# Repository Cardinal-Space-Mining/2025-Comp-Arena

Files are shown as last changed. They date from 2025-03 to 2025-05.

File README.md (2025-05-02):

# 2025-Comp-Arena

This is the arena for the 2025 COSMIC Competition at ISU.

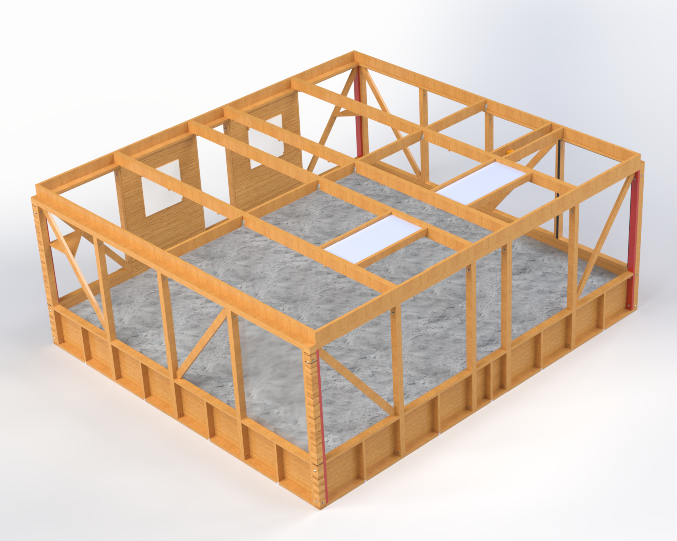
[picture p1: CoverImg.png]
arena image


## BOM
[here](https://docs.google.com/spreadsheets/d/1-_N2USS-mLNvjBXAtTUOFBfuuMwFibqy-OpLSeePz_4/edit?usp=sharing)

## Construction Outline
1. Recieve shipment of lumber on 5/16/2025 at 8 am when SICTR wood shop opens.
2. Use SICTR 1211 to cut wood to length, pre cut straps, and pre cut vapor barriers
3. Store cut wood over night 5/16 to 5/17 in SICTR 1248
4. Use SICTR 1211 to assemble arena Panels
5. Store fabbed Panels over night 5/17 to 5/18 in SICTR 1248
6. Assemble Panels into base arena
7. Store base arena overnight 5/18 - 5/19 in SICTR 1248
8. Have regolith delivered by sponsor, and moved in by FP&M
9. Emplace final vapor barrier
10. Install Dehumidifier
11. Store regolith and arena overnight 5/19 - 5/20 in SICTR 1248
12. Install cameras, shelves, visionary-S, and networking setup
13. Store regolith and arena overnight 5/20 - 5/21 in SICTR 1248
14. Checkin Begins

### Lumber Cuting Instructions
Cut boards according to this cut list:
```
For: 1x1, Cost: 35.0, Effiency: 84.82%
	Purchase List:
		(2) ankeny HomeDepot 1x1x10'
	Cut List:
		(1) ankeny HomeDepot 1x1x10' -> [3.0, 3.0, 3.0, 3.0, 3.0, 3.0, 3.0, 3.0, 3.0, 20.11, 20.11, 20.11, 31.0]
		(1) ankeny HomeDepot 1x1x10' -> [3.0, 3.0, 3.0, 3.0, 3.0, 3.0, 3.0, 3.0, 3.0, 3.0, 3.0, 3.0, 3.0, 3.0, 3.0, 3.0, 3.0, 20.11, 31.0]

For: 2x4, Cost: 230.79, Effiency: 83.63%
	Purchase List:
		(49) ames menards 2x4x12'
	Cut List:
		(1) ames menards 2x4x12' -> [21.0, 48.0]
		(4) ames menards 2x4x12' -> [21.0, 24.0, 48.0, 48.0]
		(5) ames menards 2x4x12' -> [21.0, 21.0, 21.0, 80.0]
		(8) ames menards 2x4x12' -> [24.0, 45.0, 73.2]
		(8) ames menards 2x4x12' -> [45.0, 80.0]
		(23) ames menards 2x4x12' -> [48.0, 80.0]

For: 2x6, Cost: 300.96, Effiency: 72.99%
	Purchase List:
		(18) ames menards 2x6x20'
	Cut List:
		(1) ames menards 2x6x20' -> [45.0, 45.0, 45.0, 45.0, 45.0]
		(1) ames menards 2x6x20' -> [45.0]
		(1) ames menards 2x6x20' -> [21.0, 196.0]
		(2) ames menards 2x6x20' -> [223.0]
		(2) ames menards 2x6x20' -> [24.0, 199.0]
		(2) ames menards 2x6x20' -> [45.0, 48.0, 48.0, 48.0, 48.0]
		(9) ames menards 2x6x20' -> [196.0]

```
Cut list generated by [CutListOptimizer1D](https://github.com/wimos-ai/CutListOptimizer1D)

### Panel Assembly Instructions

#### Basic Panel:

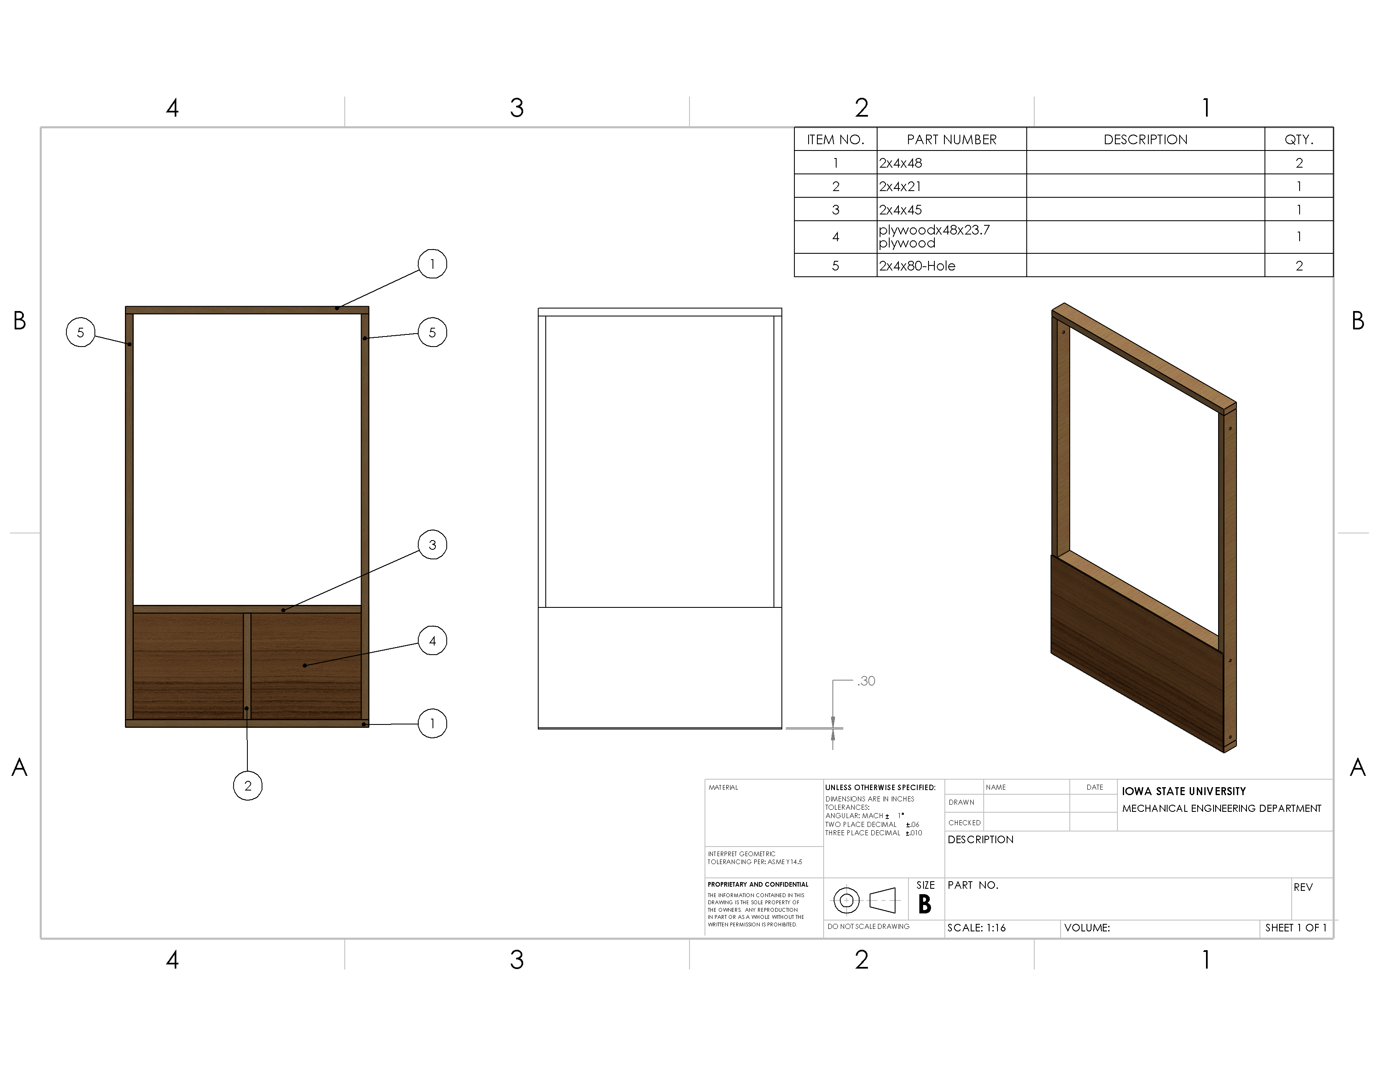
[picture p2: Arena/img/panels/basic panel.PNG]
Basic Panel png


#### Basic Panel (B):

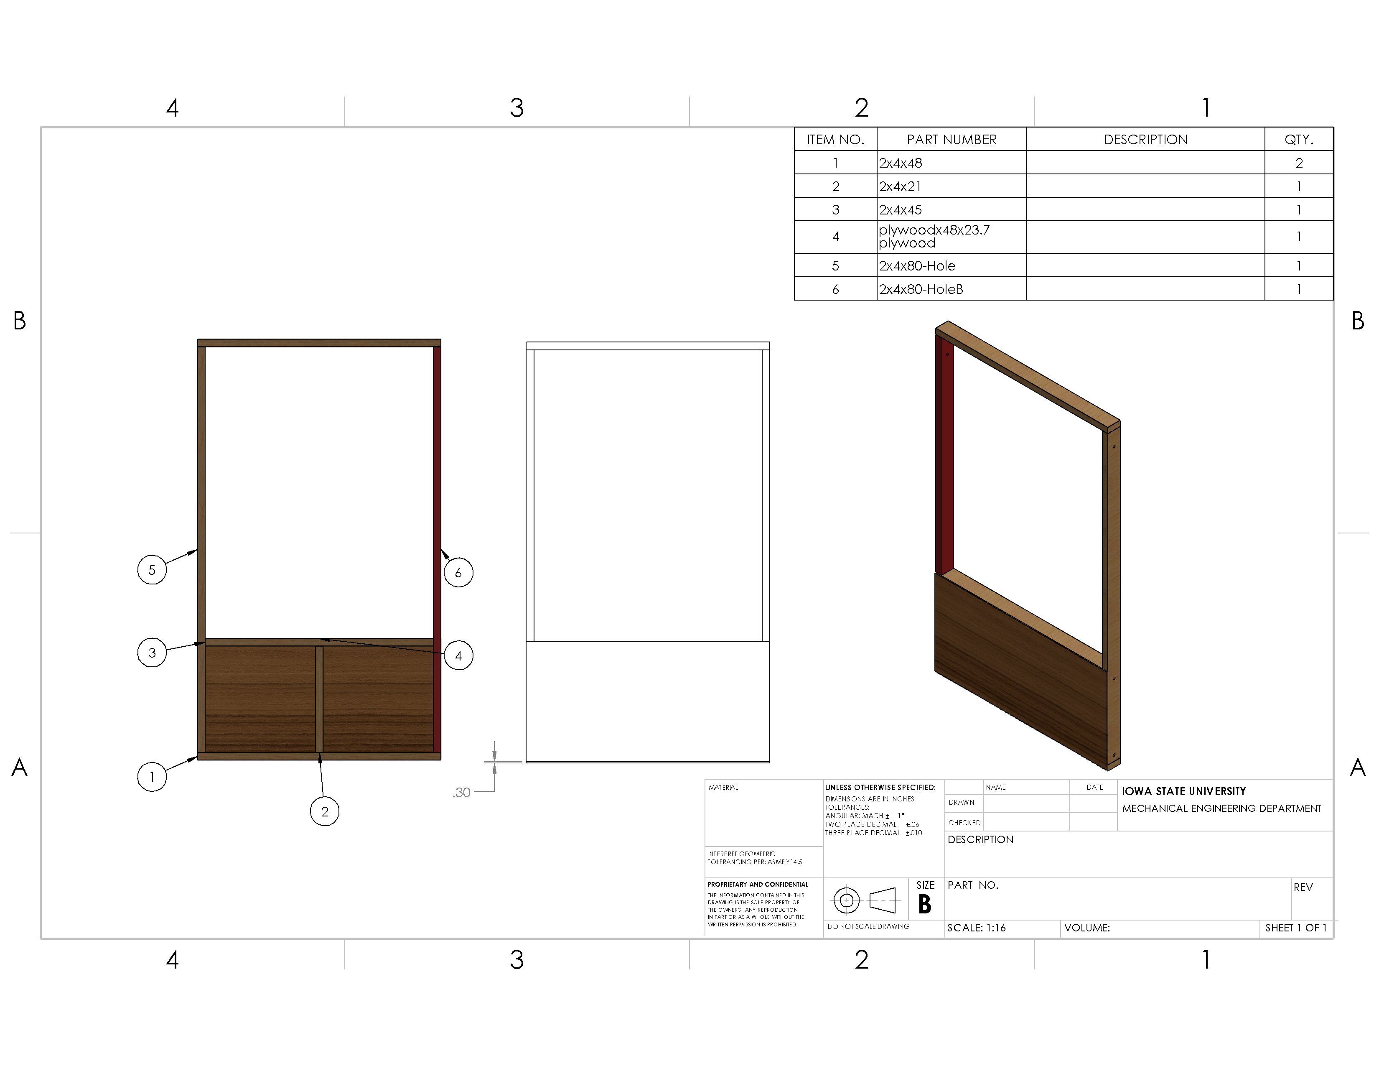
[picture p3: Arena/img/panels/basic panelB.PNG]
Basic Panel (B) png


#### Basic Panel (C):

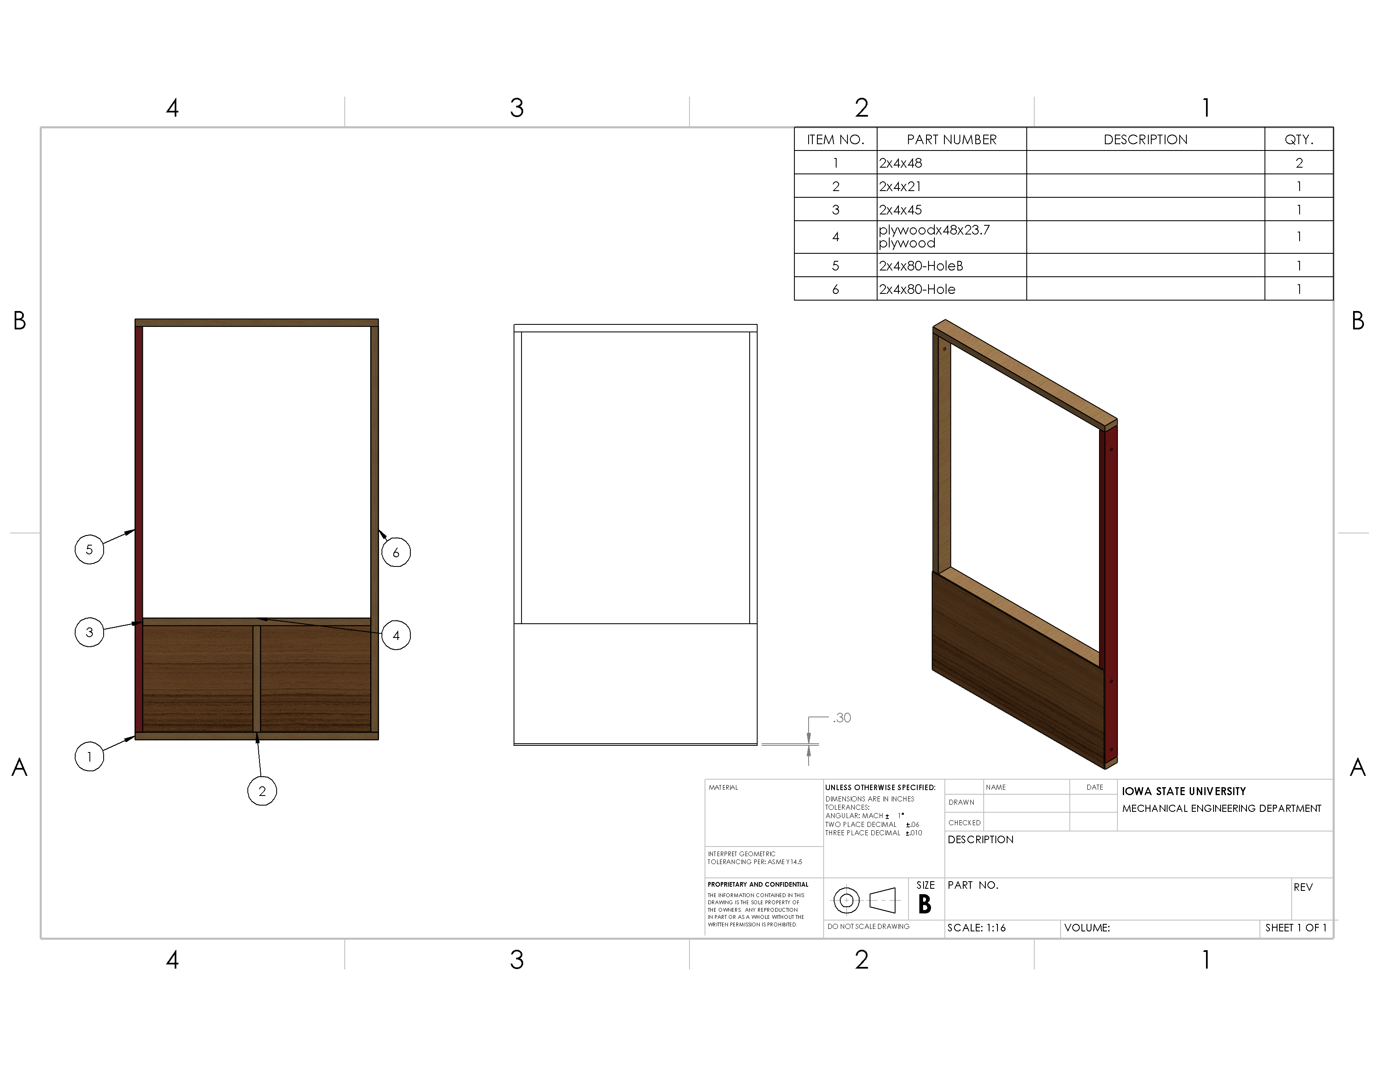
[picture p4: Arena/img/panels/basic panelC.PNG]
Basic Panel (C) png


#### Short Panel:

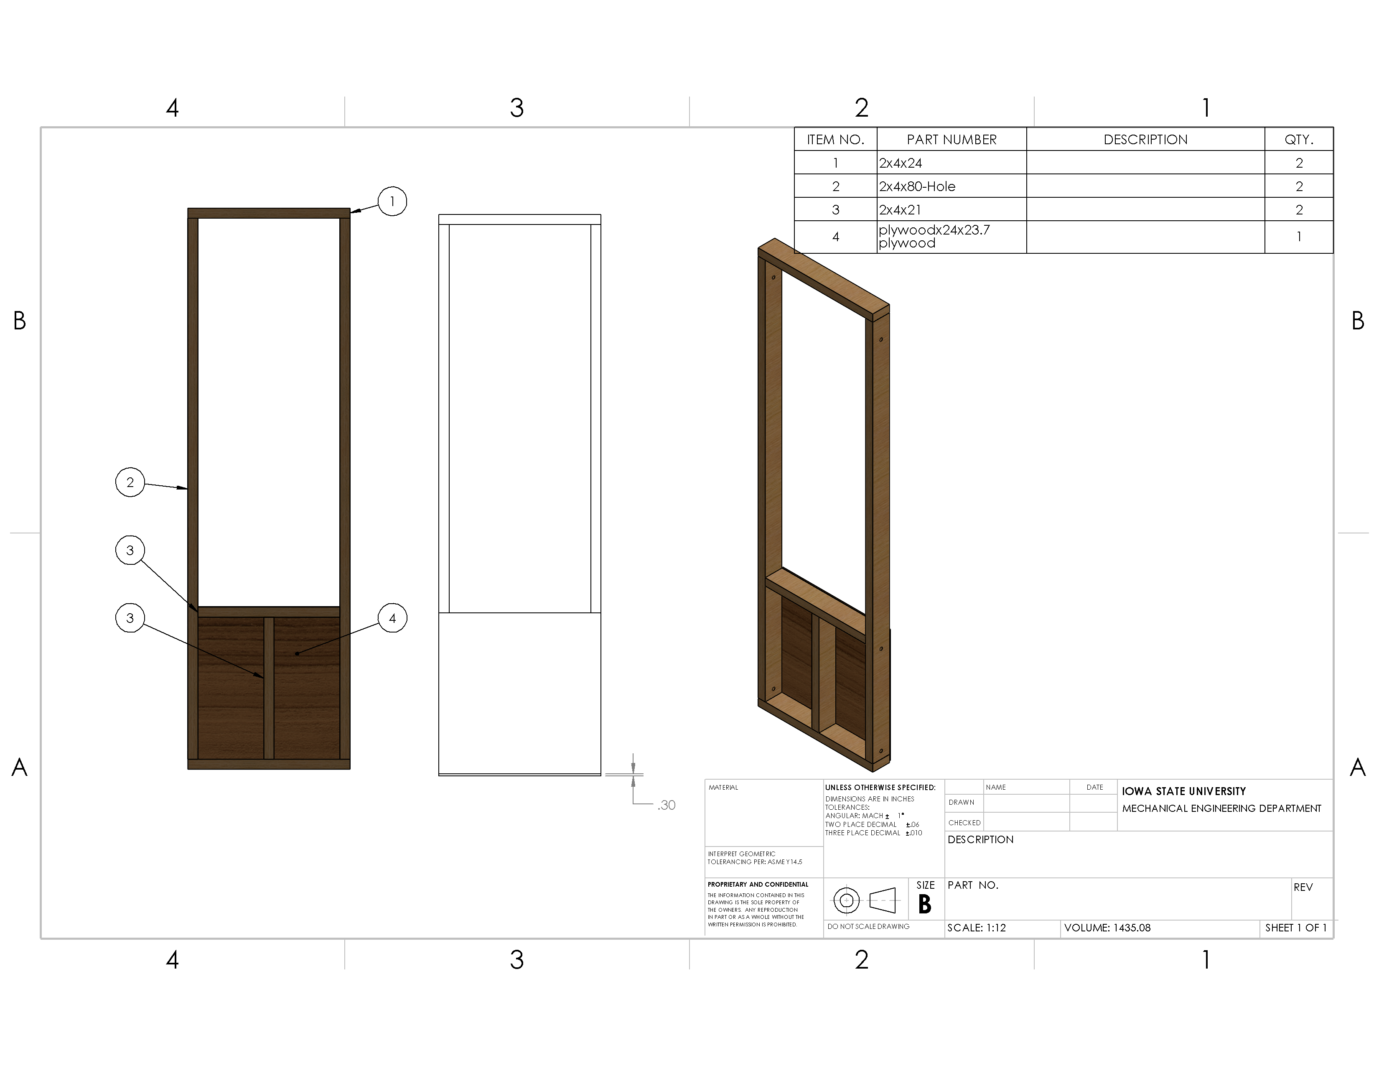
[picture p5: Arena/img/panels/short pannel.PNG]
Short Panel png


#### Door Panel:

It's just a basic panel with different sheeting

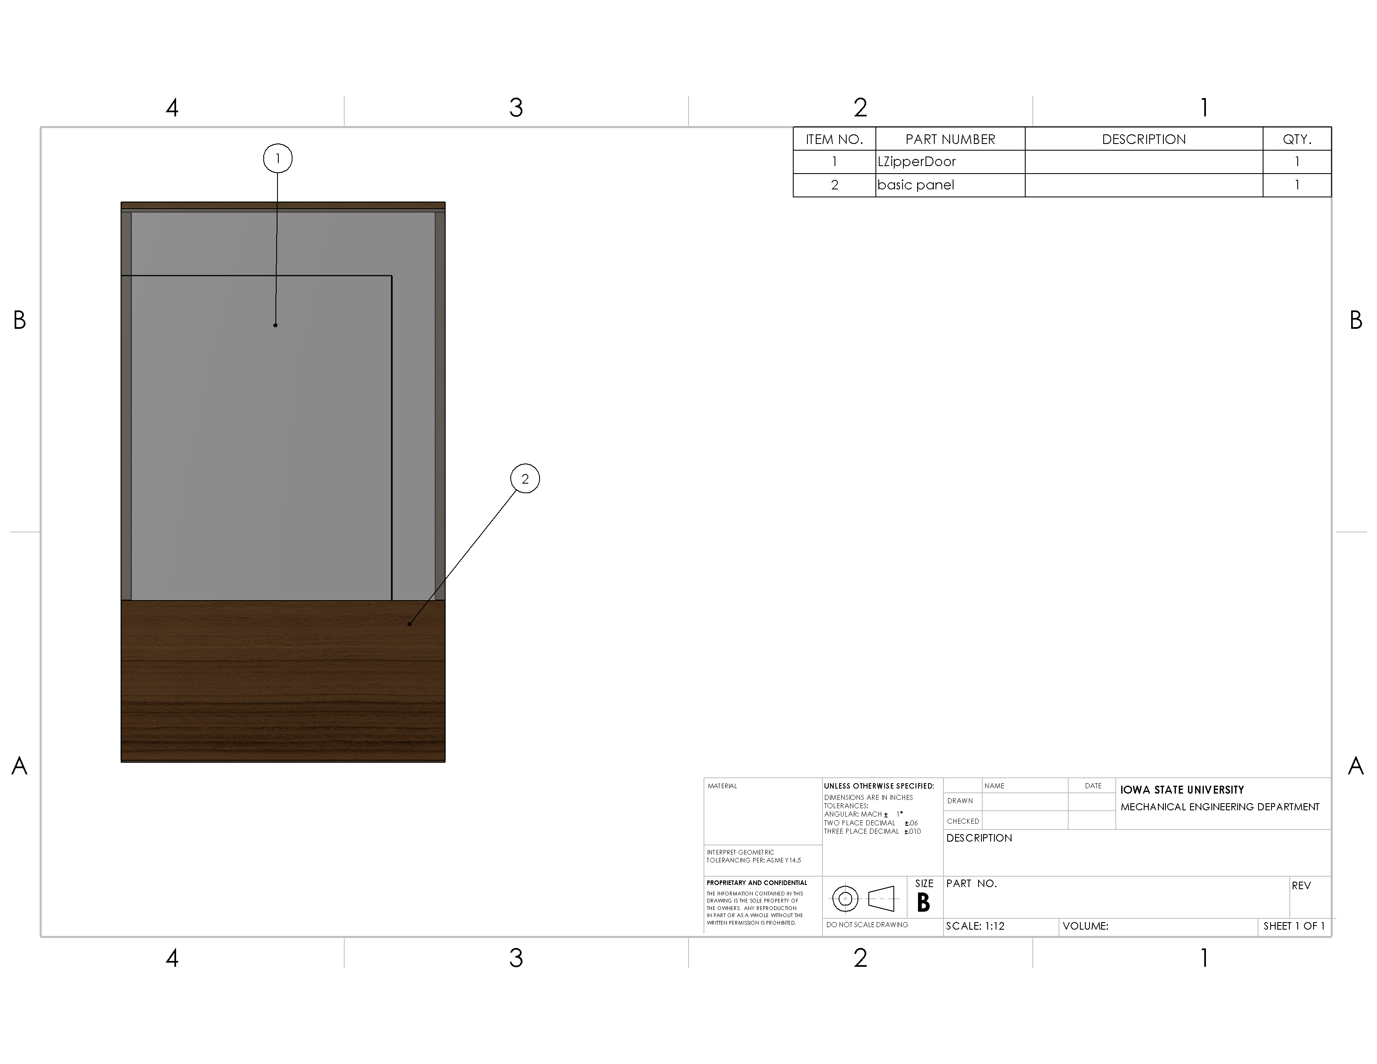
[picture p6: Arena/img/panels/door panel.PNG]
Door Panel png


#### Fan Panel:

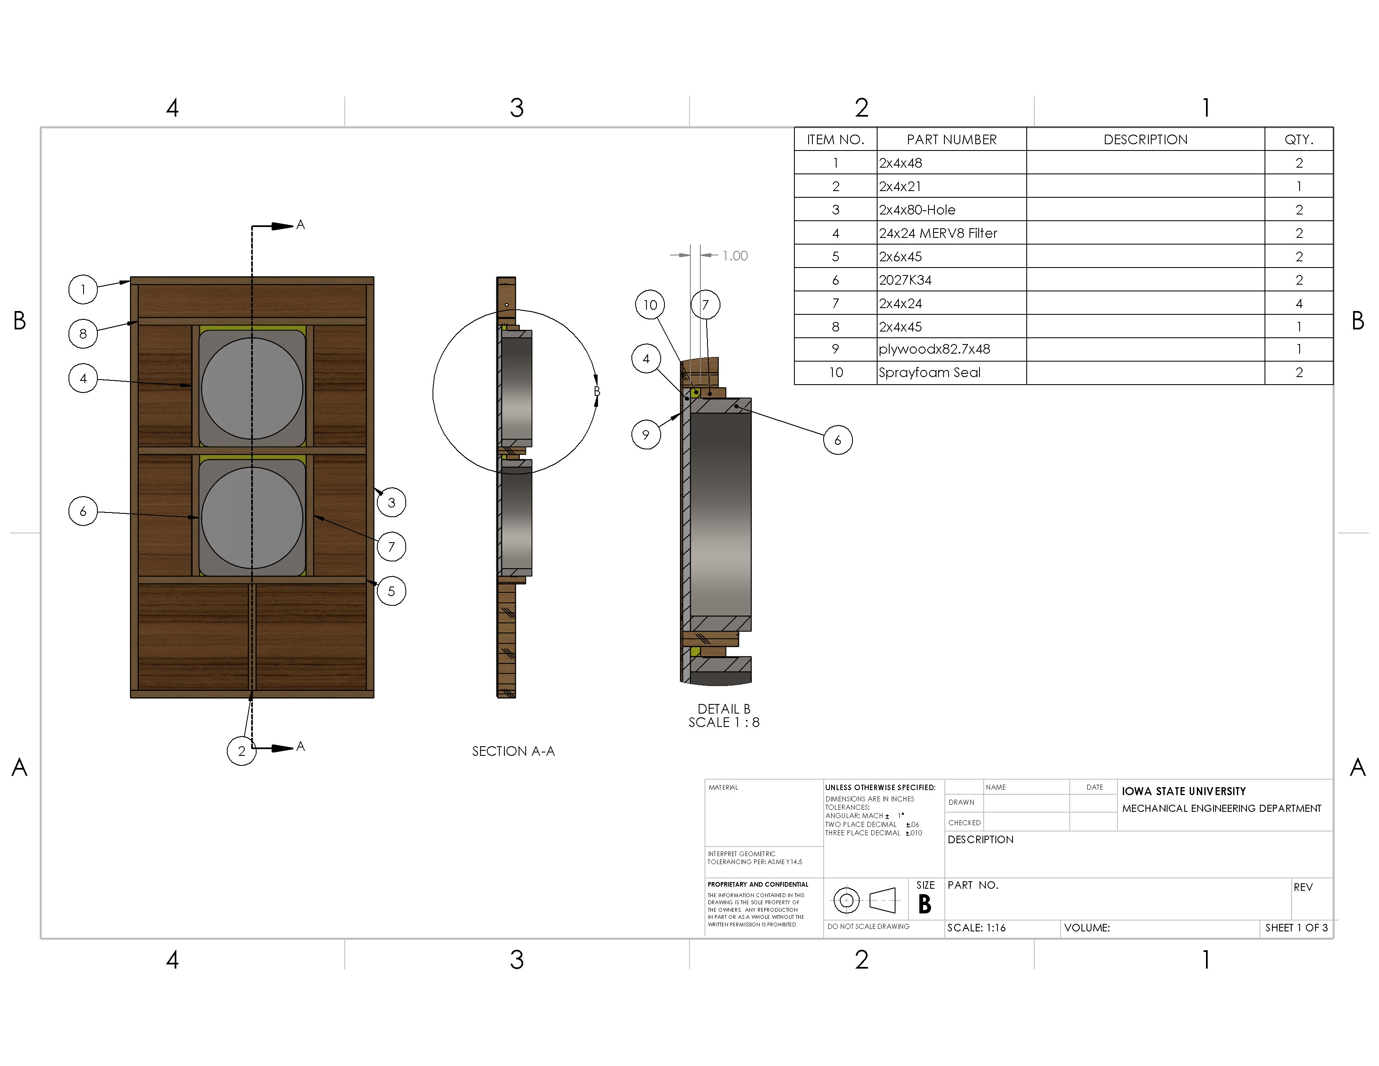
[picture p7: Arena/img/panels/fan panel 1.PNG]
Fan Panel (1) png


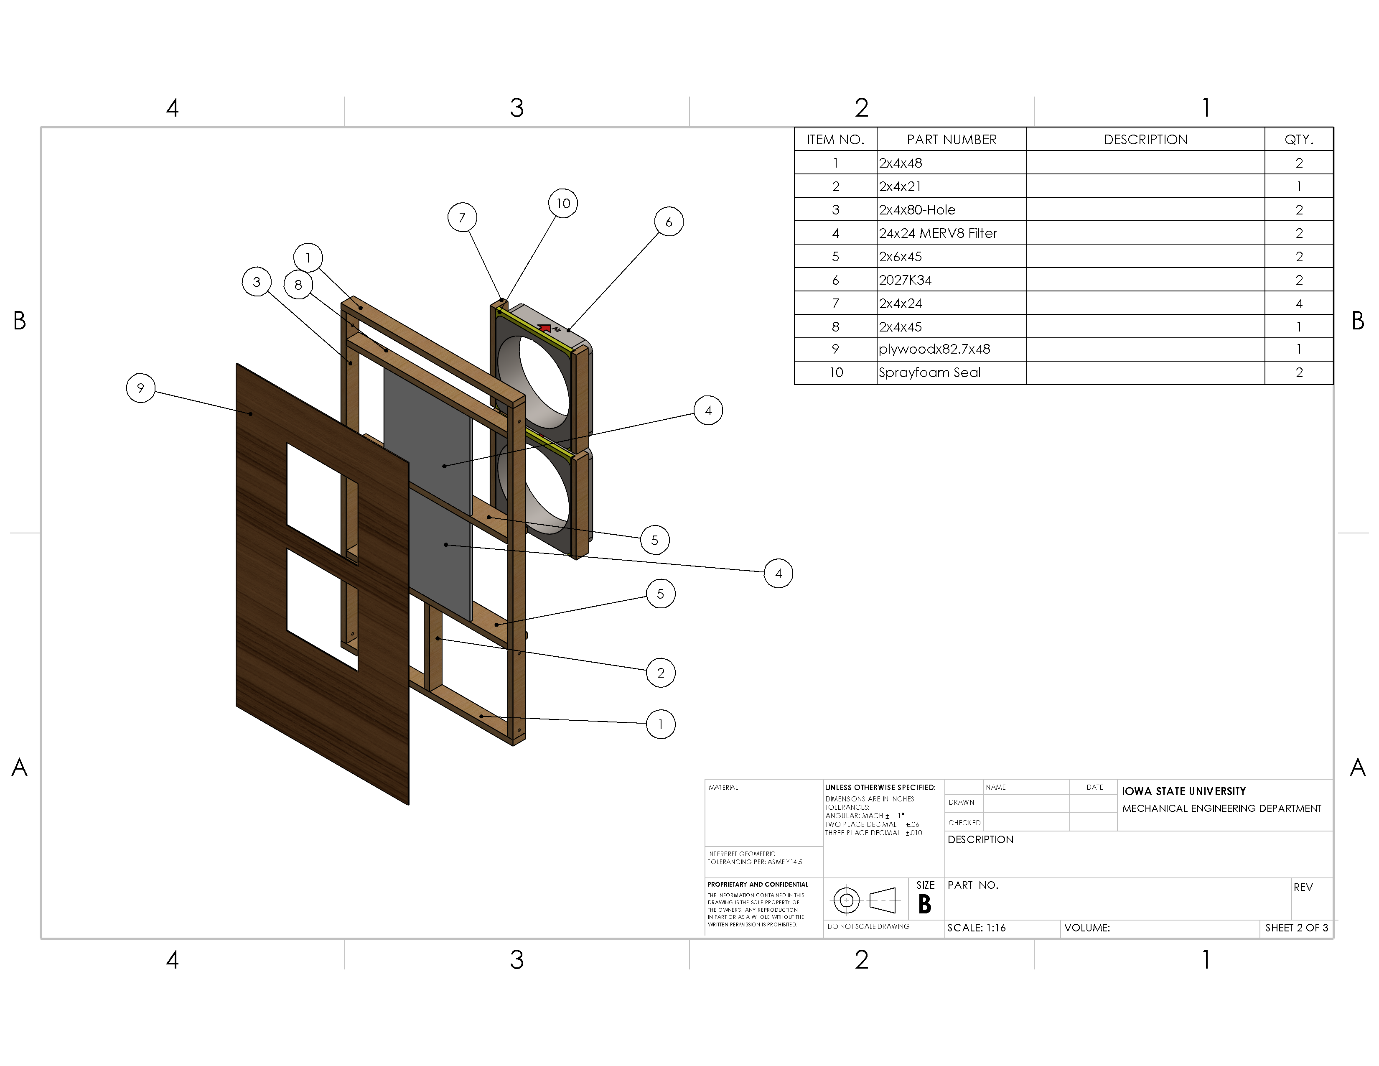
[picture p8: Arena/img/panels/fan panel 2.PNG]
Fan Panel (2) png


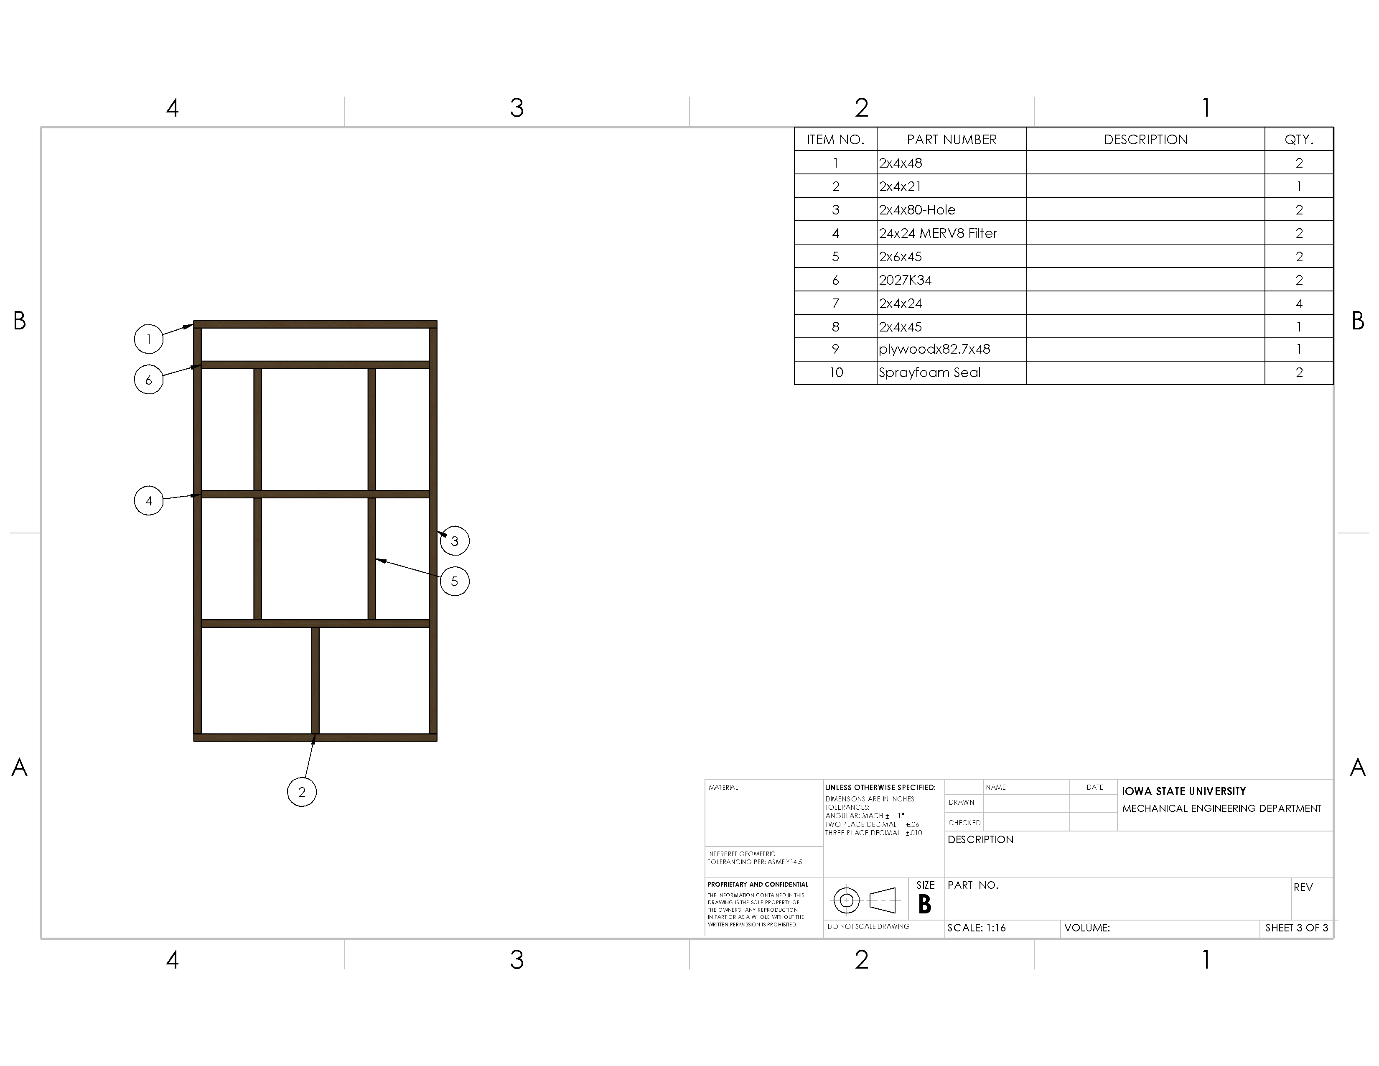
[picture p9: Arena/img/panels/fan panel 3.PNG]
Fan Panel (3) png


### Arena Assembly Instructions

1. Install Floor
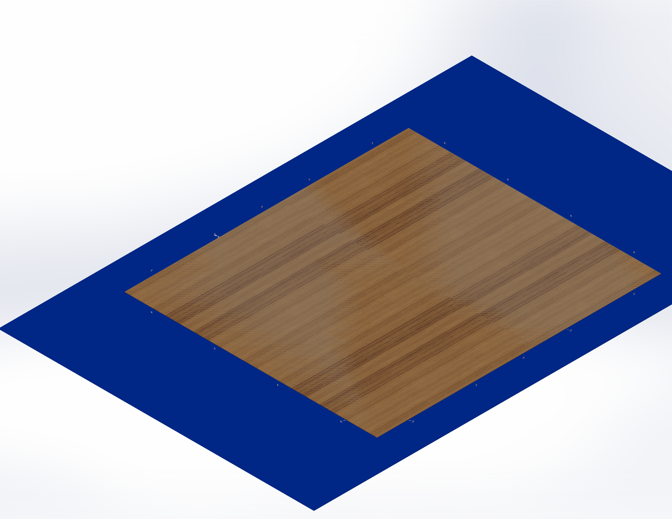
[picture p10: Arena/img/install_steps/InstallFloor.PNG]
Install Floor
	
2. Install Walls, Bracing, and Sheeting
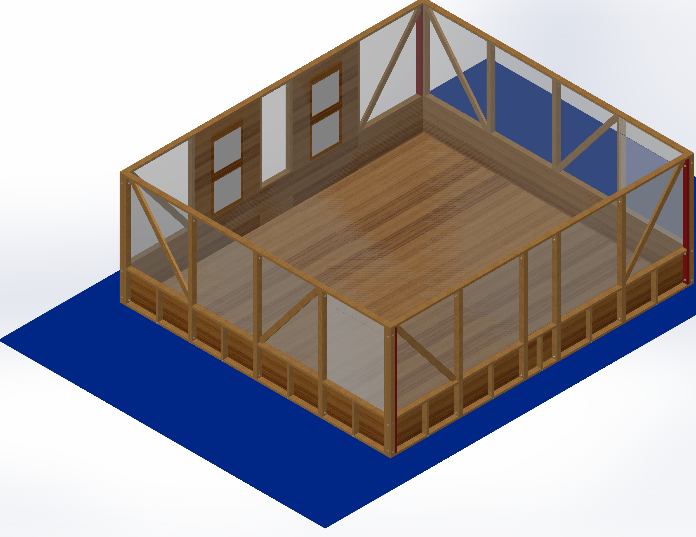
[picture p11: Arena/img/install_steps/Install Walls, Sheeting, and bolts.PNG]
Install Wall

3. Install Crown
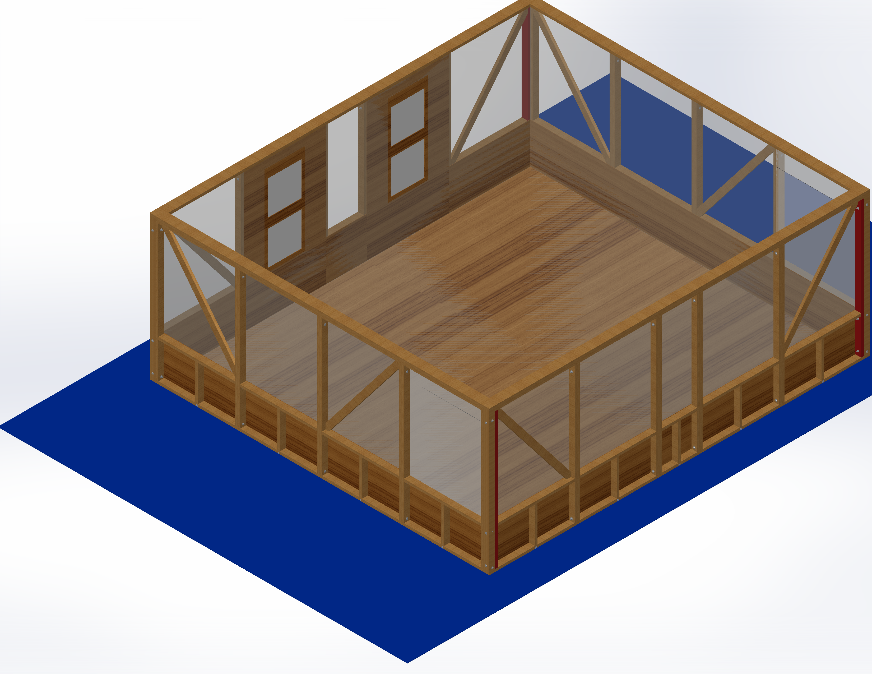
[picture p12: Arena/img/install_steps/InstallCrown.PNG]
InstallCrown

4. Add Regolith
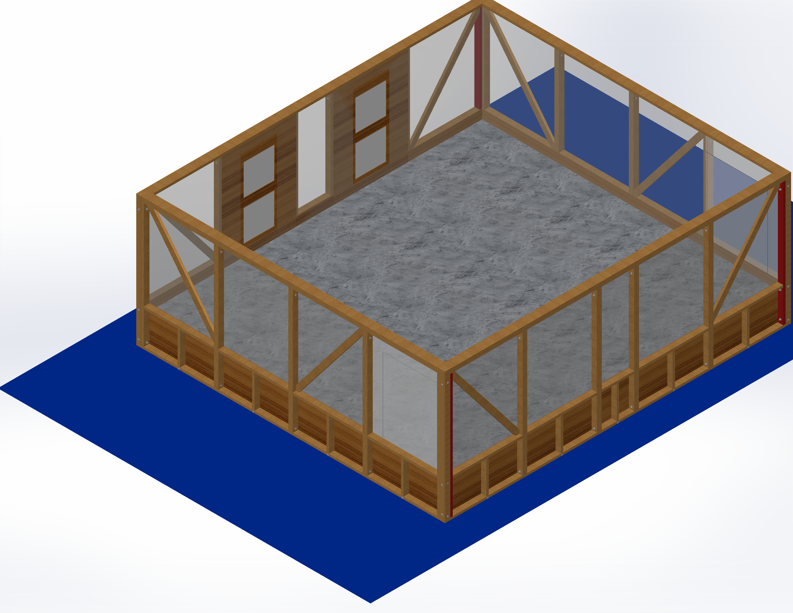
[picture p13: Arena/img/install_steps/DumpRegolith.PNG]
DumpLime

5. Add Roof
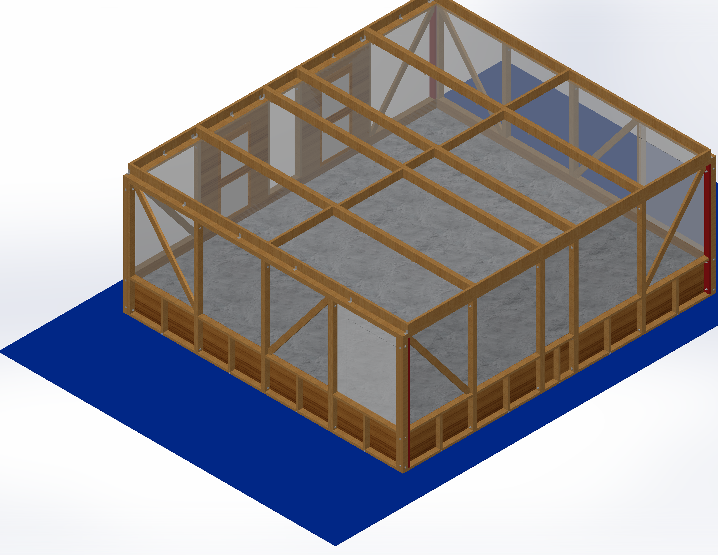
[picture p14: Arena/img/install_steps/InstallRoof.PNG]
AddRoof


### Arena Disassembly Instructions
1. Remove Roof
DumpLime
2. Remove Walls
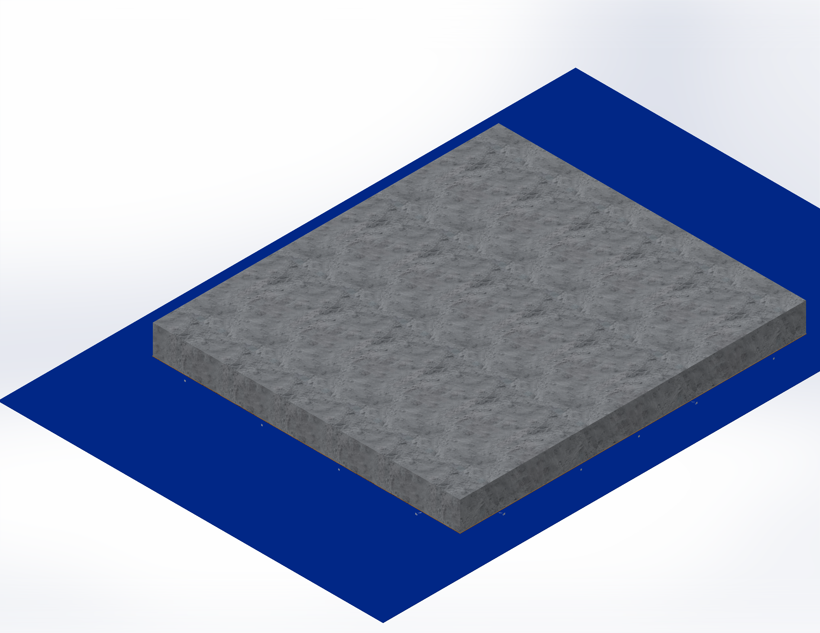
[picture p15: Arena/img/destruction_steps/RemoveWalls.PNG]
Remove Walls

3. Remove Regolith
Remove Regolith
4. Remove tarp and flooring

### FP&M Loading and Unloading Procedures

#### Loading: 
1. Rougly 21 tons of Ag Lime will be delivered by 18 Wheeler in a dump trailer, then dumped in the SICTR parking lot
	* Like [here](https://youtu.be/68cE22GQ5mw?si=_lyoBhohsE822YJR&t=146)
2. The Ag Lime will be moved by Mini-skid into the Arena Shell
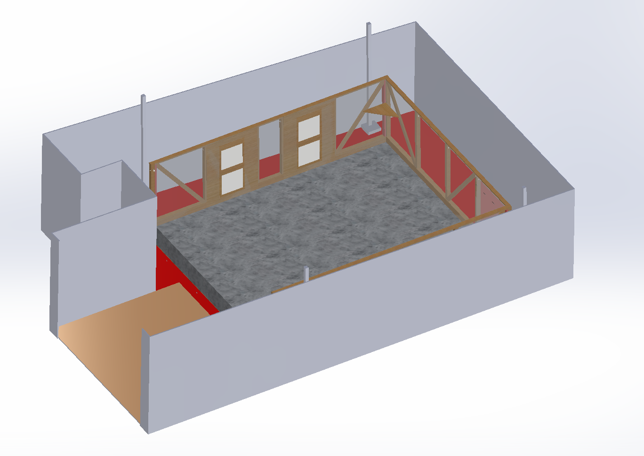
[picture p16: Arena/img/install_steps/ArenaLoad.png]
	* 

#### Unloading: 

1. The roof and wall will be removed by CSM volunteers. Ag Lime will be moved by Mini-skid into a 18 wheeler
	* Remove Regolith

#### Notes:
* The door width is 10 ft
* The ceiling height is:
	* 14 ft in orange zone
	* 8 ft in red zone

#### SDS Sheets:
* [Ag Lime](https://www.graymont.com/sites/default/files/users/user2883/NZ%20SDS/Agricultural%20Lime%20NZ%20GHS%20SDS%202022-10-05.pdf)
* [Playground Sand (Reference)](https://www.quikrete.com/pdfs/msds-b4-playsand.pdf)
* [Top Soil (Reference)](https://www.countymaterials.com/en/downloads/industry-tech-documents/safety-data-sheets-sds/459-topsoil-potting-soil-safety-data-sheet-sds/file)

### Volumetric Properties
| Catagory| Volume (in^3) |
| :--- | :---: |
| Total Volume | 861625.87 | 
| Regolith Volume |  743268.12 | 
| Non-Regolith Volume | 118357.74 |
| Wood Volume | 82497.11 | 
| Plastic Volume |  30002.63 | 
| Iron Volume  | 97.22 |

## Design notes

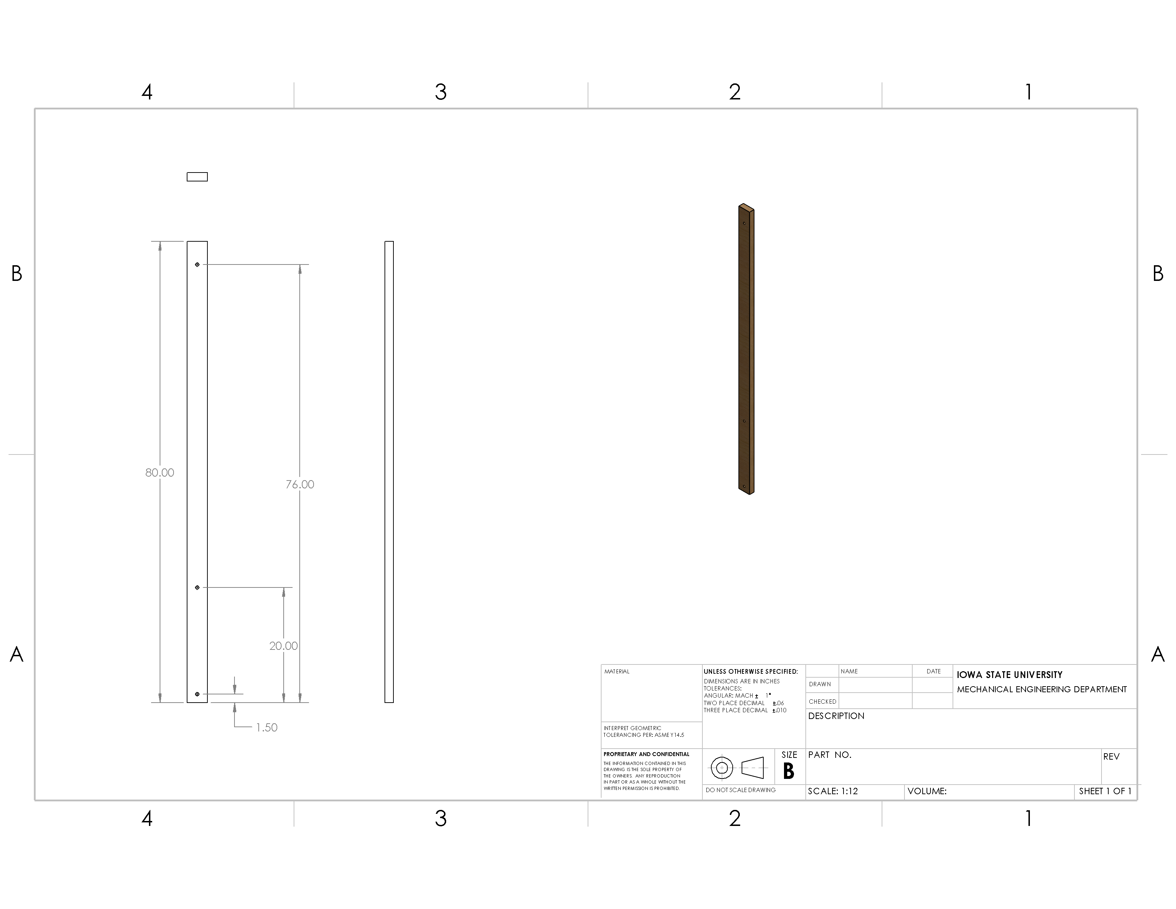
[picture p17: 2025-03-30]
Arena/img/2x4s/2x4x80-Hole.PNG

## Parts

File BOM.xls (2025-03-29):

ITEM NO. | PART NUMBER | DESCRIPTION | QTY.
1 | pbx48x96 particle board |  | 8
2 | pbx24x96 particle board |  | 2
3 | Tie Strap 199in |  | 5
4 | Tie Strap 223in |  | 4
5 | plastic sheeting 216x192 |  | 2
6 | 2x4x48 |  | 32
7 | 2x4x21 |  | 20
8 | 2x4x45 |  | 16
9 | plywoodx48x23.775 plywood |  | 14
10 | 2x4x80-Hole |  | 32
11 | 2x4x24 |  | 12
12 | plywoodx24x23.775 plywood |  | 2
13 | 2x4x73.02 |  | 8
14 | 92141A033 | 18-8 Stainless Steel Washer | 132
15 | 95462A033 | Medium-Strength Steel Hex Nut | 66
16 | 2x4x80-HoleB |  | 4
17 | plastic sheeting 216x82.78 |  | 1
18 | LZipperDoor |  | 2
19 | plastic sheeting door |  | 2
20 | 24x24 MERV8 Filter |  | 4
21 | 2x6x45 |  | 8
22 | 2027K34 |  | 4
23 | plywoodx82.78125x48 |  | 2
24 | Sprayfoam Seal |  | 4
25 | plastic sheeting 216x82.78-fan |  | 1
26 | 4x4x83 |  | 4
27 | 2x6x196 |  | 10
28 | 2x6x48 |  | 8
29 | 2x6x24 |  | 2
30 | A21Z |  | 52
31 | 2x6x21 |  | 1
32 | 1x1x3 |  | 26
33 | Regolith |  | 1
34 | 1x1x20.11 |  | 4
35 | plywoodxshelf plywood |  | 2
36 | 1x1x31 |  | 2
37 | 91247A728 | Medium-Strength Grade 5 Steel Hex Head Screw | 42
38 | 91247A736 | Medium-Strength Grade 5 Steel Hex Head Screw | 24

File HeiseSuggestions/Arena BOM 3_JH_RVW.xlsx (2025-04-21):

ITEM NO. | PART NUMBER | DESCRIPTION | QTY.
34 | 1x1x20.11 |  | 4
32 | 1x1x3 |  | 26
36 | 1x1x31 |  | 2
22 | 2027K34 |  | 4
20 | 24x24 MERV8 Filter |  | 4
7 | 2x4x21 |  | 20
11 | 2x4x24 |  | 12
8 | 2x4x45 |  | 16
6 | 2x4x48 |  | 32
13 | 2x4x73.02 |  | 8
10 | 2x4x80-Hole |  | 32
16 | 2x4x80-HoleB |  | 4
27 | 2x6x196 |  | 10
41 | 2x6x199-Chamfered |  | 2
42 | 2x6x223-Chamfered |  | 2
31 | 2x6x21 |  | 1
29 | 2x6x24 |  | 2
21 | 2x6x45 |  | 8
28 | 2x6x48 |  | 8
26 | 4x4x83 |  | 4
37 | 91247A728 | Medium-Strength Grade 5 Steel Hex Head Screw | 42
38 | 91247A736 | Medium-Strength Grade 5 Steel Hex Head Screw | 24
14 | 92141A033 | 18-8 Stainless Steel Washer | 132
15 | 95462A033 | Medium-Strength Steel Hex Nut | 66
30 | A21Z |  | 52
18 | LZipperDoor |  | 2
2 | pbx24x96 particle board |  | 2
1 | pbx48x96 particle board |  | 8
5 | plastic sheeting 216x192 |  | 2
17 | plastic sheeting 216x82.78 |  | 1
25 | plastic sheeting 216x82.78-fan |  | 1
19 | plastic sheeting door |  | 2
12 | plywoodx24x23.775 plywood |  | 2
9 | plywoodx48x23.775 plywood |  | 14
23 | plywoodx82.78125x48 |  | 2
35 | plywoodxshelf plywood |  | 2
33 | Regolith |  | 1
24 | Sprayfoam Seal |  | 4
3 | Tie Strap 199in |  | 5
4 | Tie Strap 223in |  | 4
Purchase Order
Name | Related Item Number | vendor url | unit cost | qty | Cumulative Cost
menards 2x4x12ft | 7, 11, 8, 6, 13, 10, 16 | here (https://www.menards.com/main/building-materials/lumber-boards/dimensional-lumber/2-x-4-construction-framing-lumber/1021127/p-1444422744154-c-13125.htm) | 4.71 | 54 | 254.34
menards 2x6x20ft | 27, 31, 29, 21, 28 | here (https://www.menards.com/main/building-materials/lumber-boards/dimensional-lumber/2-x-6-construction-framing-lumber/1021813/p-1444422749853-c-13125.htm) | 16.72 | 20 | 334.4
Home Depot 1x1xX | 34, 32, 36 | here (https://www.homedepot.com/p/Weaber-1-in-x-1-in-x-Random-Length-S4S-Oak-Board-21073/207059032) | 1.75 | 22 | 38.5
menards 4x4x8ft | 26 | here (https://www.menards.com/main/building-materials/lumber-boards/timbers-logs/4-x-4-2-southern-yellow-pine-timber/1022412/p-1444422751242-c-13131.htm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) | 9.25 | 4 | 37
McMaster Box Fan (2027K34) (Buy local - see below) | 22 | here (https://www.mcmaster.com/catalog/131/758/2027K34) | 41.66 | 4 | 166.64
MERV8 Filter 3 Pack (Alternate suggested - see below) | 20 | here (https://www.homedepot.com/p/HDX-24-in-x-24-in-x-1-in-Standard-Pleated-Furnace-Air-Filter-FPR-5-MERV-8-3-Pack-HDX3P5-012424/314671500) | 12.69 | 3 | 38.07
Poly Cover Clear Polyethylene Plastic Sheeting 10 mil 20ft x 100ft | 2025-05-17 | here (https://farmplasticsupply.com/construction/clear-plastic-sheeting) | 144.99 | 1 | 144.99
Poly Cover Clear Polyethylene Plastic Sheeting 4 mil 20ft x 100ft | 2025-05-17 | here (https://farmplasticsupply.com/construction/clear-plastic-sheeting) | 79.99 | 1 | 79.99
4x8x.25" Plywood Sheets | 12, 9, 23, 35 | here (https://www.homedepot.com/p/Plytanium-1-4-in-x-4-ft-x-8-ft-BC-Sanded-Pine-Plywood-235552/100063669) | 24.92 | 13 | 323.96
4x4x.25 Particle Board Sheets | 2025-01-02 | here (https://www.homedepot.com/p/1-4-in-x-4-ft-x-8-ft-OSB-Utility-Panel-300985/100025804) | 12.58 | 10 | 125.8
Regolith (Ag lime 432 ft^3) (90lbs./ cubic foot) so we need 20 tons | 33 | here (https://www.bergeronmaterials.com/aglime/) | 20 | 20 | 400
Spray Foam | 24 | here (https://www.menards.com/main/paint/caulks-sealants/spray-foam-rubberized-sealant/great-stuff-trade-gaps-cracks-expanding-spray-foam-12-oz/11106955/p-144443596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) | 4.38 | 5 | 21.9
Screws (2in) * See below |  |  | 0 | 0 | 0
Screws (4in) ^ See below |  |  | 0 | 0 | 0
Staples
48 in. x 86.4 in. Plastic Dust Barrier Zipper Door Kit L-type Other | 19 | here (https://www.homedepot.com/p/Wellco-48-in-x-86-4-in-Plastic-Dust-Barrier-Zipper-Door-Kit-L-type-Other-Screen-Door-DBZ122201L/328366107) | 18.09 | 3 | 54.27
92141A033 - 1/2" flat washer (pack of 50) |  | here (https://www.mcmaster.com/catalog/131/3682/92141A033) | 7.12 | 3 | 21.36
95462a033 - 1/2"-13 Hx Nut (pack of 100) |  | here (https://www.mcmaster.com/catalog/131/3645/95462A033) | 29.99 | 1 | 29.99
91247A728 - 1/2"-13 x 4" Gr 5 Hx Bolt (pack of 10) | 37 | here (https://www.mcmaster.com/catalog/131/3587/91247A728) | 14.76 | 6 | 88.56
91247A736 - 1/2"-13 x 6" Gr 5 Hx Bolt (pack of 5) | 38 | here (https://www.mcmaster.com/catalog/131/3587/91247A736) | 12.2 | 7 | 85.4
A21Z Angle Brackets (See comments of arena markup) | 30 | here (https://www.homedepot.com/p/Simpson-Strong-Tie-2-in-x-1-1-2-in-x-1-3-8-in-ZMAX-Galvanized-Angle-A21Z/100375047) | 0.9 | 52 | 46.8
1 1/2 Inch Mil-Spec 17337 Nylon (300 ft roll) (Where use?) | 2025-03-04 | here (https://www.strapworks.com/1-12-inch-milspec-17337-nylon-foliage-green) | 167.94 | 1 | 167.94
Large Tarp |  | here (https://www.amazon.com/Multi-Purpose-Material-Waterproof-Tarpaulin-Canopy/dp/B081B8XYH7) | 48.87 | 1 | 48.87
 |  |  |  |  | 2508.78
Heise Review Additions - recommended, not required.
Alternate 7000CFM fan at Walmart (local purchase) | 22 | here (https://www.walmart.com/ip/Hyper-Tough-New-20-inch-High-Velocity-Sealed-Motor-Drum-Fan-with-Wall-Mount/334273417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) | 77.32 | 2 | 154.64
Alternate MERV8 air filters @ Menards 24x24x2 (more flow) | 20 | here (https://www.menards.com/main/heating-cooling/air-filters/true-blue-standard-capacity-2-merv-8-pleated-air-filter/fb24x24x2qfb2g/p-1481267970012-c-6856.htm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) | 8.99 | 6 | 53.94
#9 x 2" Construction Screws - 1LB (~ 112 screws) |  | here (https://www.menards.com/main/hardware/fasteners-connectors/screws/wood-screws/grip-fast-reg-premium-9-x-2-star-drive-steel-flat-head-interior-construction-scr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) | 7.79 | 3 | 23.37
#9 X 2-1/2" Construction Screws - 1LB (~100 screws) |  | here (https://www.menards.com/main/hardware/fasteners-connectors/screws/wood-screws/grk-reg-r4-trade-9-x-2-1-2-star-drive-gold-flat-head-exterior-framing-screw-100-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) | 17.99 | 4 | 71.96
#8 x 1-1/4" Constr. Screw - 1LB (~190 screws) |  | here (https://www.menards.com/main/hardware/fasteners-connectors/screws/deck-screws/grip-fast-reg-8-x-1-1-4-star-drive-tan-flat-head-triple-coated-exterior-deck-scr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) | 8.87 | 1 | 8.87
Joist hangers |  | here (https://www.menards.com/main/hardware/fasteners-connectors/construction-hardware/structural-hangers/mitek-reg-triple-zinc-slant-nail-joist-hanger/jus26-tz/p-1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) | 1.86 | 10 | 18.6

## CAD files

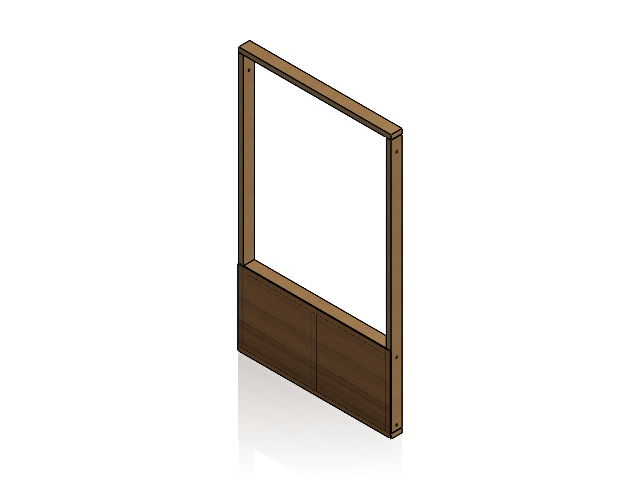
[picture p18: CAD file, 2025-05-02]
Arena/panels/basic panelB.SLDASM
2x4x48 x 2
2x4x21
2x4x45
plywoodx48x23.7 plywood
2x4x80-Hole
2x4x80-HoleB

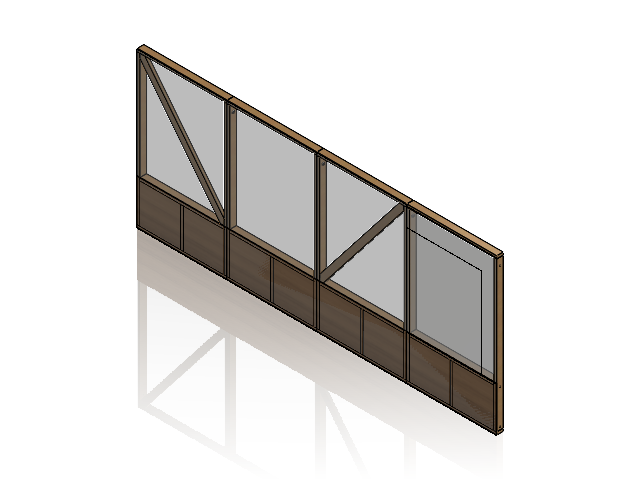
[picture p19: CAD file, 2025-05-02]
Arena/walls/doorWallm.SLDASM
2x4x48 x 8
2x4x21 x 4
2x4x45 x 4
plywoodx48x23.7 plywood x 4
2x4x80-Hole x 8
2x4x73.02 x 2
LZipperDoor
plastic sheeting door
91247A728_Medium-Strength Grade 5 Steel Hex Head Screw x 9
95462A033_Medium-Strength Steel Hex Nut x 9
92141A033_18-8 Stainless Steel Washer x 18

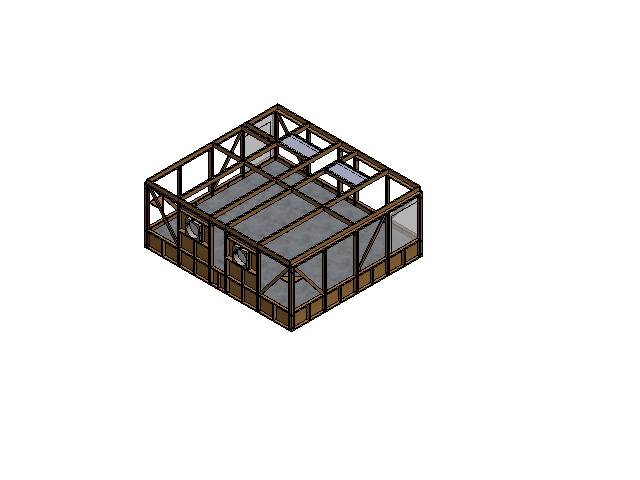
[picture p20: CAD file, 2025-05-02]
Arena/Arena.SLDASM
pbx48x96 particle board x 8
pbx24x96 particle board x 2
Tie Strap 199in x 5
Tie Strap 223in x 4
plastic sheeting 216x192
2x4x48 x 32
2x4x21 x 20
2x4x45 x 26
plywoodx48x23.7 plywood x 14
2x4x80-Hole x 32
2x4x24 x 10
plywoodx24x23.7 plywood x 2
2x4x73.02 x 8
91247A728_Medium-Strength Grade 5 Steel Hex Head Screw x 42
95462A033_Medium-Strength Steel Hex Nut x 66
92141A033_18-8 Stainless Steel Washer x 132
2x4x80-HoleB x 4
LZipperDoor x 2
plywoodx82.7x48 x 2
Sprayfoam Seal x 2
2x6x45 x 8
2027K34 x 2
24x24 MERV8 Filter x 2
1x1x2 x 4
4x4x83 x 4
2x6x196 x 10
2x6x48 x 8
2x6x24 x 2
1x1x3 x 26
45x21 MERV8 Filter x 2
lu24 x 10
2x6x21
91247A736_Medium-Strength Grade 5 Steel Hex Head Screw x 24
Regolith
1x1x20.11 x 4
plywoodxshelf plywood x 2
1x1x31 x 2
V3S##2-######A-S249638
2x6x199-Chamfered x 2
2x6x223-Chamfered x 2

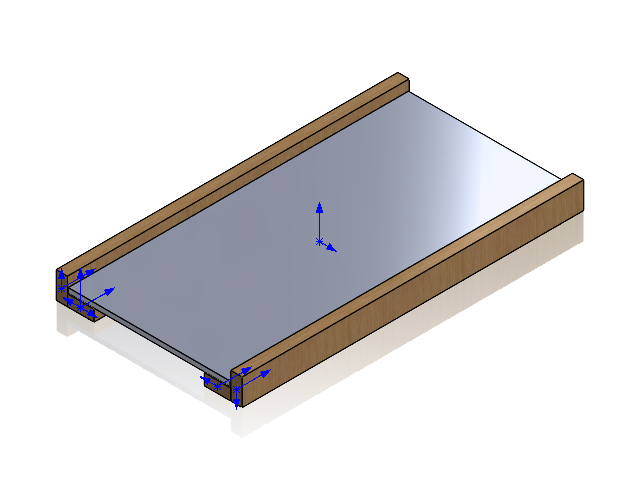
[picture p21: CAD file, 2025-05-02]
Arena/walls/FilterCradle.SLDASM
2x4x45 x 4
45x21 MERV8 Filter

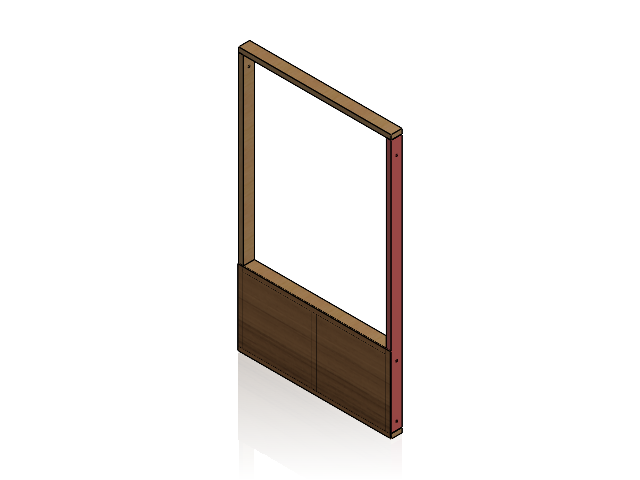
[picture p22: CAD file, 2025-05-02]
Arena/panels/basic panelC.SLDASM
2x4x48 x 2
2x4x21
2x4x45
plywoodx48x23.7 plywood
2x4x80-HoleB
2x4x80-Hole

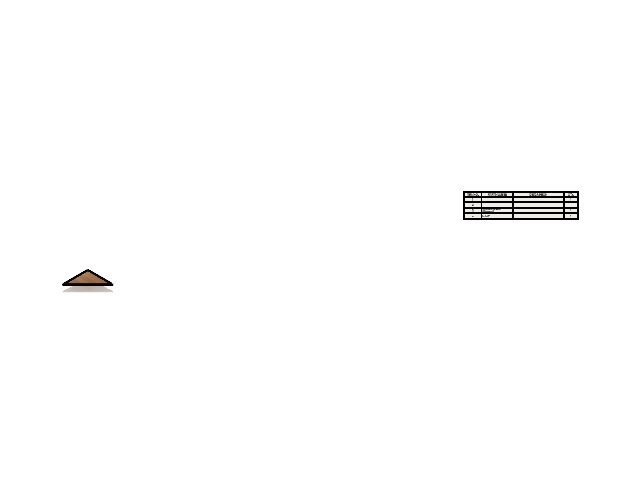
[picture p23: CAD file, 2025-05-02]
Arena/Shelf.SLDASM
1x1x3
1x1x20.11 x 2
plywoodxshelf plywood
1x1x31

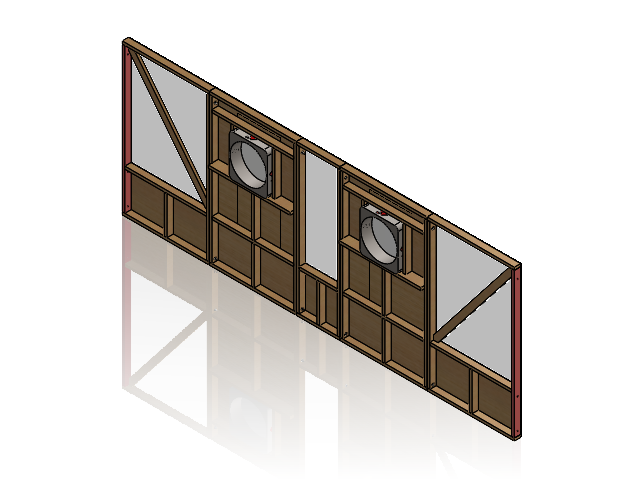
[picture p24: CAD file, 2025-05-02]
Arena/walls/fanWall.SLDASM
2x4x24 x 8
2x4x80-Hole x 8
2x4x21 x 6
plywoodx24x23.7 plywood
2x4x73.02 x 2
2x4x48 x 8
plywoodx82.7x48 x 2
Sprayfoam Seal x 2
2x4x45 x 6
2x6x45 x 2
2027K34 x 2
24x24 MERV8 Filter x 2
1x1x2 x 4
plastic sheeting 216x82.78-fan
91247A728_Medium-Strength Grade 5 Steel Hex Head Screw x 12
95462A033_Medium-Strength Steel Hex Nut x 12
92141A033_18-8 Stainless Steel Washer x 24
plywoodx48x23.7 plywood x 2
2x4x80-HoleB x 2

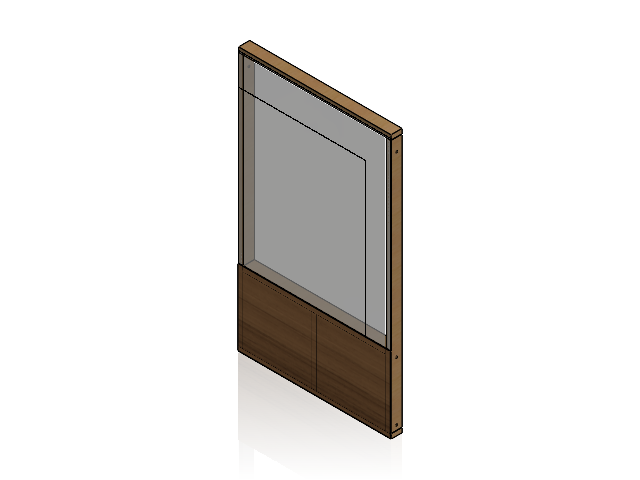
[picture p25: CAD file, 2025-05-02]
Arena/panels/door panel.SLDASM
LZipperDoor
2x4x48 x 2
2x4x21
2x4x45
plywoodx48x23.7 plywood
2x4x80-Hole x 2

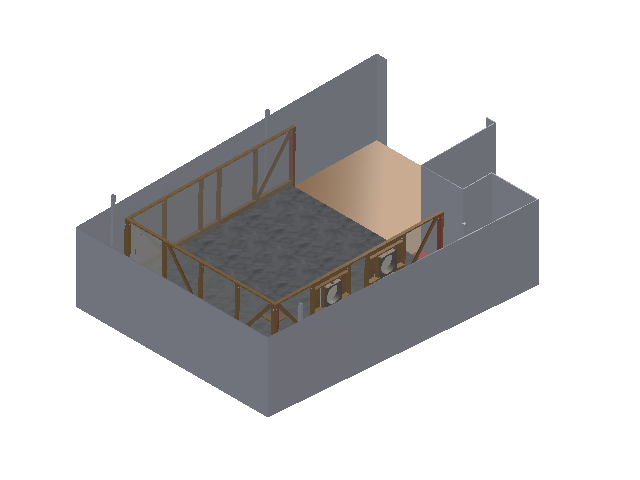
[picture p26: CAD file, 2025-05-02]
Arena/ArenaFit.SLDASM
Comp. Room
Tie Strap 199in x 5
Tie Strap 223in x 4
plastic sheeting 216x192
2x4x48 x 24
2x4x21 x 16
2x4x45 x 12
plywoodx48x23.7 plywood x 10
2x4x80-Hole x 24
2x4x24 x 12
plywoodx24x23.7 plywood x 2
2x4x73.02 x 6
91247A728_Medium-Strength Grade 5 Steel Hex Head Screw x 33
95462A033_Medium-Strength Steel Hex Nut x 57
92141A033_18-8 Stainless Steel Washer x 114
2x4x80-HoleB x 4
plastic sheeting 216x82.78
LZipperDoor
plastic sheeting door
24x24 MERV8 Filter x 4
2x6x45 x 4
2027K34 x 4
plywoodx82.7x48 x 2
Sprayfoam Seal x 4
plastic sheeting 216x82.78-fan
4x4x83 x 4
91247A736_Medium-Strength Grade 5 Steel Hex Head Screw x 24
Regolith
1x1x3
1x1x20.11 x 2
plywoodxshelf plywood
1x1x31

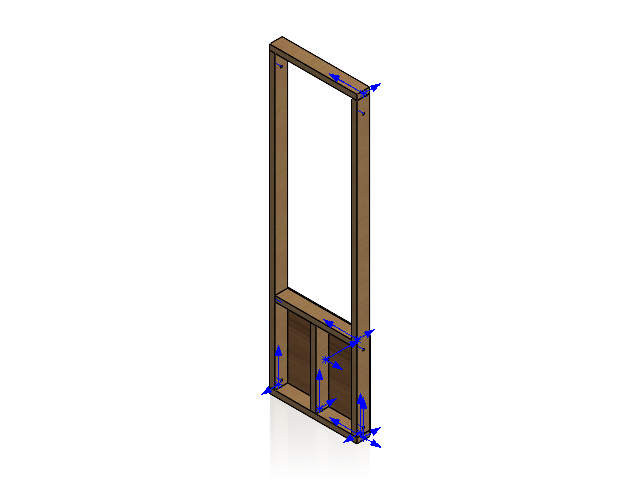
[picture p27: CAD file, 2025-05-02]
Arena/panels/short pannel.SLDASM
2x4x24 x 2
2x4x80-Hole x 2
2x4x21 x 2
plywoodx24x23.7 plywood

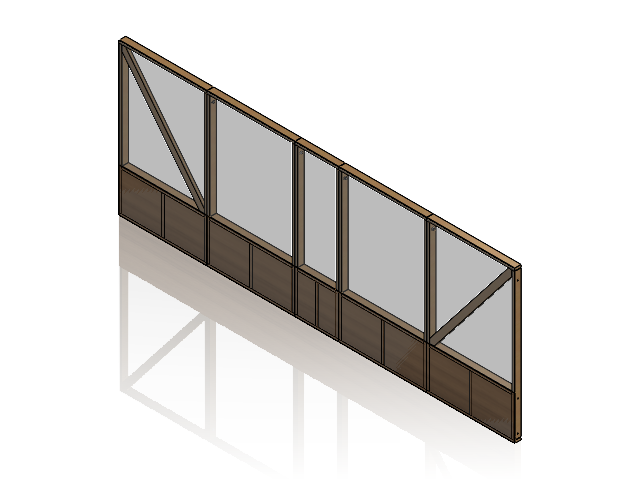
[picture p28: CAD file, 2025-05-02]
Arena/walls/basicWall.SLDASM
2x4x48 x 8
2x4x21 x 6
2x4x45 x 4
plywoodx48x23.7 plywood x 4
2x4x80-Hole x 8
2x4x24 x 2
plywoodx24x23.7 plywood
2x4x73.02 x 2
91247A728_Medium-Strength Grade 5 Steel Hex Head Screw x 12
95462A033_Medium-Strength Steel Hex Nut x 12
92141A033_18-8 Stainless Steel Washer x 24
2x4x80-HoleB x 2
plastic sheeting 216x82.78

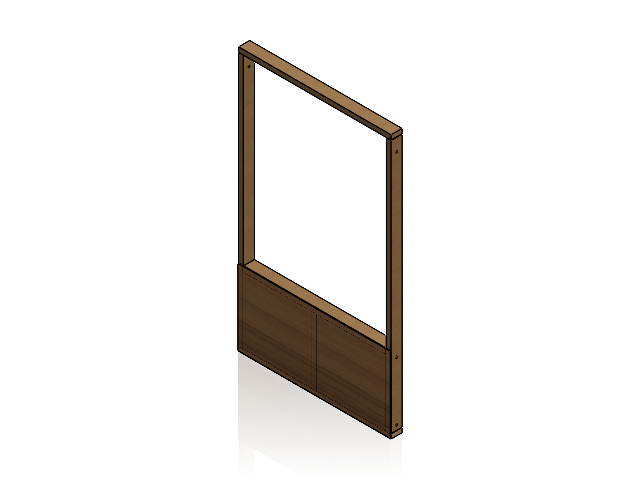
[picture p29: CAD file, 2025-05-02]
Arena/panels/basic panel.SLDASM
2x4x48 x 2
2x4x21
2x4x45
plywoodx48x23.7 plywood
2x4x80-Hole x 2

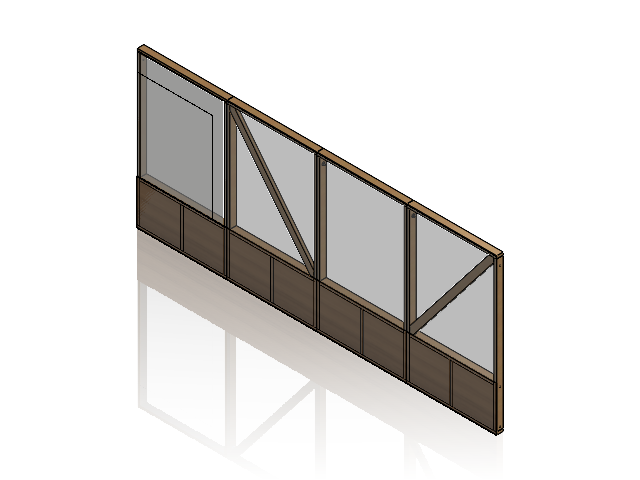
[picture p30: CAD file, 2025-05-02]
Arena/walls/doorWall.SLDASM
2x4x48 x 8
2x4x21 x 4
2x4x45 x 4
plywoodx48x23.7 plywood x 4
2x4x80-Hole x 8
LZipperDoor
2x4x73.02 x 2
plastic sheeting door
91247A728_Medium-Strength Grade 5 Steel Hex Head Screw x 9
95462A033_Medium-Strength Steel Hex Nut x 9
92141A033_18-8 Stainless Steel Washer x 18

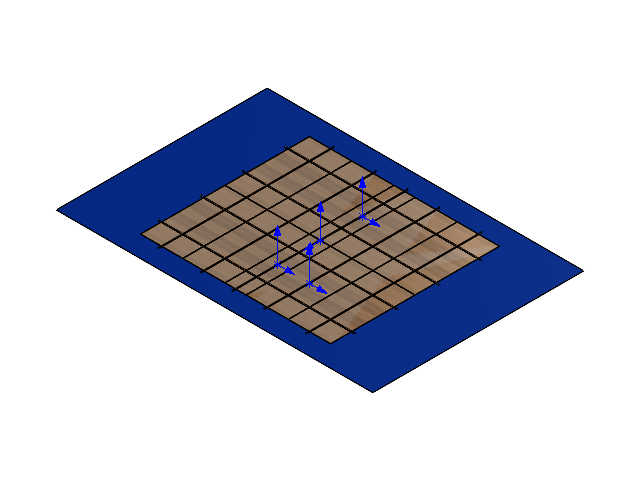
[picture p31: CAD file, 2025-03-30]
Arena/walls/floor.SLDASM
pbx48x96 particle board x 8
pbx24x96 particle board x 2
Tie Strap 199in x 5
Tie Strap 223in x 4
plastic sheeting 216x192
30x20ft Tarp

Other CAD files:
Arena/ArenaPannelForm.SLDASM
Arena/walls/crown.SLDASM
Arena/1x1s/1x1x2.SLDPRT
Arena/1x1s/1x1x20.11.SLDPRT
Arena/1x1s/1x1x3.SLDPRT
Arena/1x1s/1x1x31.SLDPRT
Arena/2x4s/2x4x21.SLDPRT
Arena/2x4s/2x4x24.SLDPRT
Arena/2x4s/2x4x41.375.SLDPRT
Arena/2x4s/2x4x45.SLDPRT
Arena/2x4s/2x4x48.SLDPRT
Arena/2x4s/2x4x57.25.SLDPRT
Arena/2x4s/2x4x65.75.SLDPRT
Arena/2x4s/2x4x73.02.SLDPRT
Arena/2x4s/2x4x80-Hole.SLDPRT
Arena/2x4s/2x4x80-HoleB.SLDPRT
Arena/2x4s/2x4x88.5.SLDPRT
Arena/2x4s/2x4xTemplate.SLDPRT
Arena/2x6s/2x6x196.SLDPRT
Arena/2x6s/2x6x199-Chamfered.SLDPRT
Arena/2x6s/2x6x199.SLDPRT
Arena/2x6s/2x6x21.SLDPRT
Arena/2x6s/2x6x223-Chamfered.SLDPRT
Arena/2x6s/2x6x24.SLDPRT
Arena/2x6s/2x6x45.SLDPRT
Arena/2x6s/2x6x48.SLDPRT
Arena/2x6s/2x6x96.SLDPRT
Arena/2x6s/2x6xTemplate.SLDPRT
Arena/4x4s/4x4x83.SLDPRT
Arena/4x4s/4x4x91.5.SLDPRT
Arena/4x4s/4x4xTemplate.SLDPRT
Arena/Comp. Room.SLDPRT
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

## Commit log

2025-01-21 Add files via upload
    Oops
    [pbx48x48 particle board.SLDPRT, plywoodx44.375x57.25.SLDPRT, plywoodx48x23.775 plywood.SLDPRT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]
2025-01-21 Fixed it for this git layout
    [1488A11_Surface-Mount Hinge with Holes.SLDPRT, 1889A54_Draw Latch.SLDPRT, 199in Tie Strap.SLDPRT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]
2025-01-22 Added gitignore. Fixed missing files
    [1488A11_Surface-Mount Hinge with Holes.SLDPRT, 1889A54_Draw Latch.SLDPRT, 199in Tie Strap.SLDPRT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]
2025-01-23 Added space fit asm from Caleb. Good job Caleb!
    [ArenaFit.SLDASM, Comp. Room.SLDPRT]
2025-01-25 fixes #2
    [Arena.SLDASM, ArenaPannelForm.SLDASM, RegolithLayout.SLDDRW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]
2025-01-25 fixes #4. Clasps are now accessable
    [Arena.SLDASM, door panel.SLDASM]
2025-01-25 Worked on #1. DNF
    [2x4x73.02.SLDPRT, Arena.SLDASM]
2025-01-25 fixes #8 & #5
    [1x1x2.SLDPRT, 1x1x31.SLDPRT, 1x1xlong.SLDPRT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]
2025-01-26 fixes #9
    [2x6x247-Chamfered.SLDPRT, Arena.SLDASM, ArenaFit.SLDASM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]
2025-01-26 I think this is everything for the first release
    [247in Tie Strap.SLDPRT, Arena.SLDASM, RegolithLayout.SLDPRT]
2025-03-01 Fixed naming conventions. Made BOM. Added short bolted connections. Need to add long bolted connections to 4x4's. Need to add roof connectors
    [1x1x20.11.SLDPRT, 2x4x80-Hole.SLDPRT, 2x6x21.SLDPRT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]
2025-03-02 Added Arena Roof hardware. Fixes #10
    [Arena.SLDASM, roof.SLDASM]
2025-03-08 Fixes #11. Fixes #12.
    [2x4x80-HoleB.SLDPRT, 4x4x83.SLDPRT, Arena.SLDASM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]
2025-03-08 Fixes #7
    [Arena.SLDASM]
2025-03-08 Updates images
    [Arena.SLDASM]
2025-03-08 Updated BOM
    [Arena.SLDASM, BOM.xls]
2025-03-29 started on #14
    [91247A728_Medium-Strength Grade 5 Steel Hex Head Screw.SLDPRT, 91247A736_Medium-Strength Grade 5 Steel Hex Head Screw.SLDPRT, 98750A107_Grade B7 Medium-Strengt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]
2025-03-30 Started on readme. Added renders of SW panel drawings for README
    [2x4x80-Hole.SLDDRW, 2x4x80-HoleB.SLDDRW, 2x4x80-HoleB.SLDPRT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]
2025-03-30 Added more drawings
    [2x4x80-HoleB.SLDDRW]
2025-03-30 Added images for install instructions
    [Arena.SLDASM, fanWall.SLDASM]
2025-03-30 Determined volume properties
    [4x4x83.SLDPRT, 91247A728_Medium-Strength Grade 5 Steel Hex Head Screw.SLDPRT, 91247A736_Medium-Strength Grade 5 Steel Hex Head Screw.SLDPRT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]
2025-04-21 Documented suggestions from Heise
    [Arena BOM 3_JH_RVW.xlsx]
2025-05-02 Fixes #15
    [45x21 MERV8 Filter.SLDPRT, Arena.SLDASM, ArenaFit.SLDASM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]
2025-05-02 FIxed Cover Image
    [Arena.SLDASM]
2025-05-17 Added Drawing
    [2x4x73.02.SLDDRW]
2025-05-20 designed 3dp mount bracket for depth camera
    [SICK_3DP_Depth_Camera_Mount.SLDPRT]
